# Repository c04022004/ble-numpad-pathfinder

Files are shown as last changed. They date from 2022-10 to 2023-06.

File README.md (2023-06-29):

# README.md

A pathfinder PCB for the upcoming Lipo-powered version of ESP32 BLE numpad. Arduino code also attached.

[Schematics PDF](./sch-export.pdf) | [Arduino Code](./arduino-freertos-code/ble_keyboard/ble_keyboard.ino) | [3D model](./3d-models/numpad-case-v10.3mf)

## Showcase

Assembled PCB  

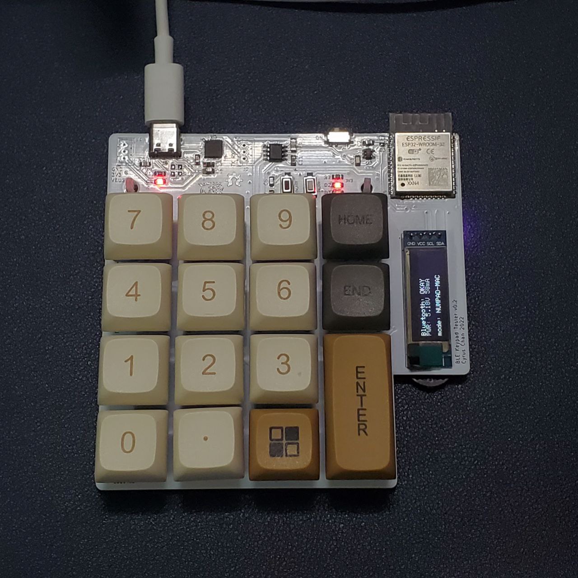
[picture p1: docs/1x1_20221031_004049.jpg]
  
</p>

Assembled PCB  w/ 3D print parts  

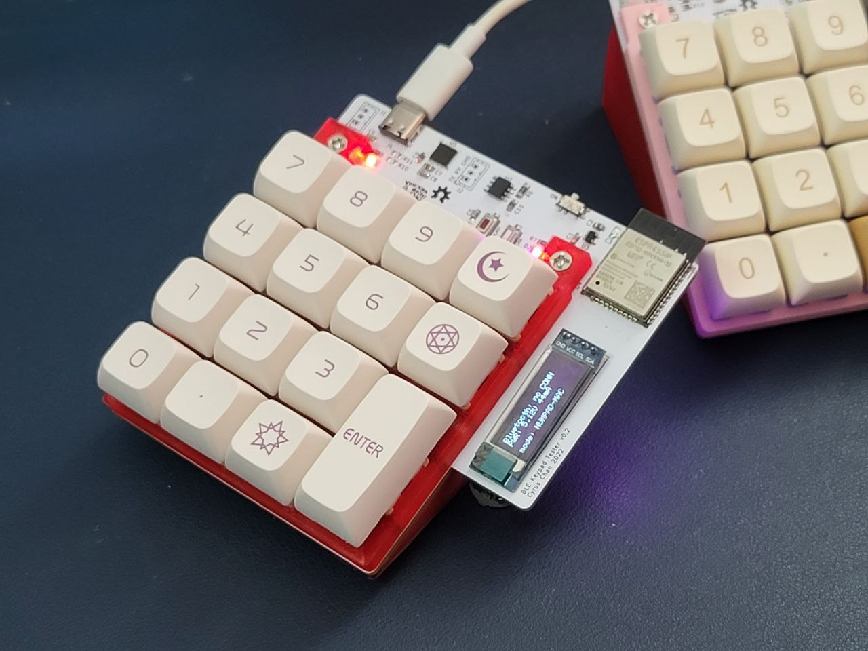
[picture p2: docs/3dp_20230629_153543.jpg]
  
</p>
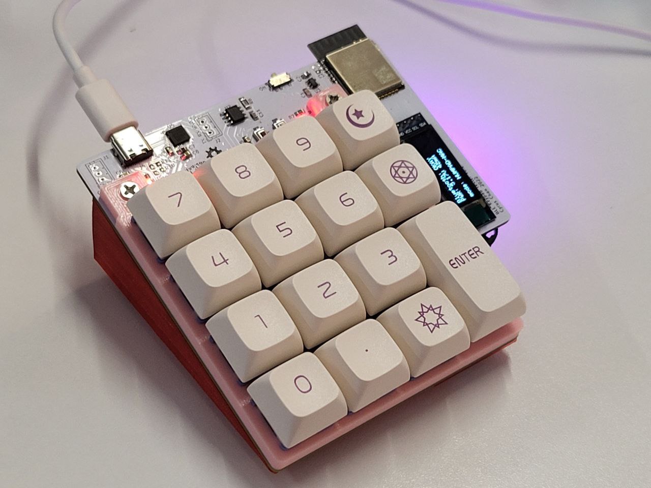
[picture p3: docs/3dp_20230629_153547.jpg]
  

## 3D-printed Parts

The two 3D printed parts (front plate & base) are fixed to the PCB asembly with 2pcs M3x20 screws.  
The parts are designed in Fusion360, and the exported files can be found at the [3d-models/](./3d-models/) folder.

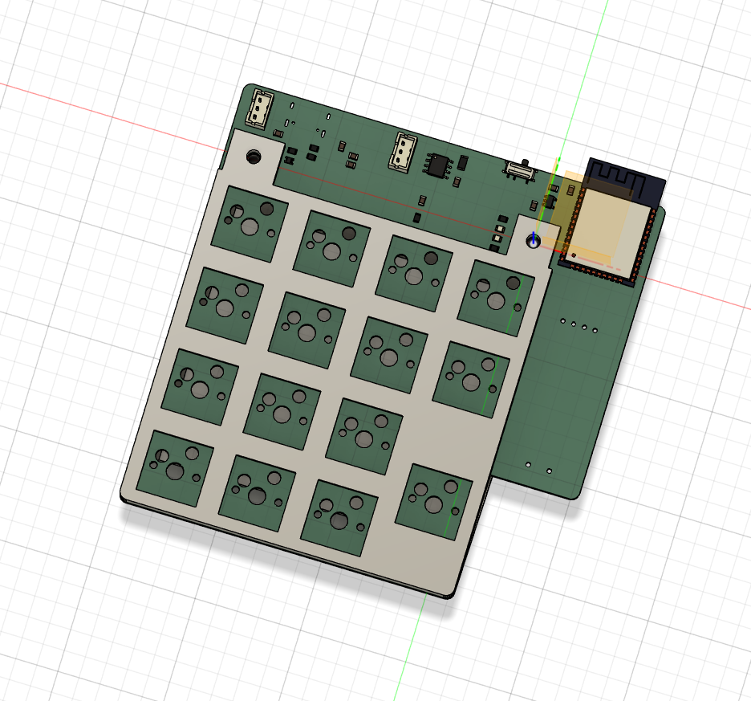
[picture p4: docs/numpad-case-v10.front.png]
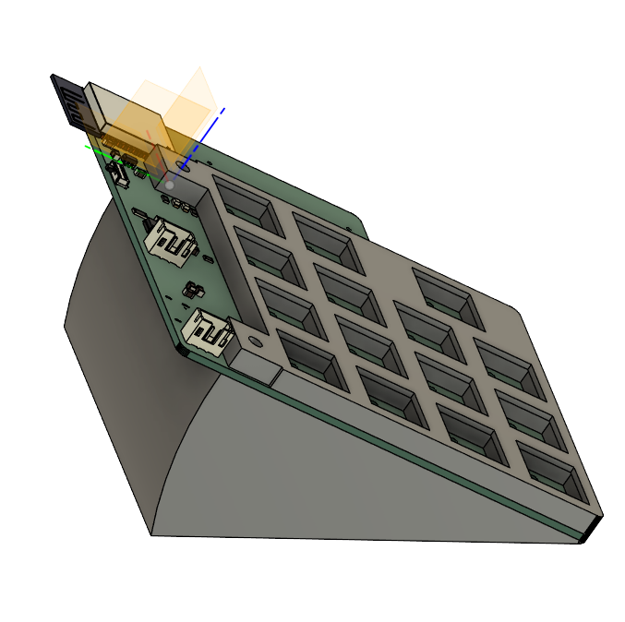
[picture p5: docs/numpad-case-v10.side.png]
 

## Known Problems
- ~~USB Type-C CC pins was lay out incorrectly~~ (still testing, maybe a USB cable compat issue)
    - Reason: CC pins should be connected to `GND` with `5.1kΩ` resistor per USB Type-C definition ([link1](https://community.silabs.com/s/article/what-s-the-role-of-cc-pin-in-type-c-solution?language=en_US) [link2](https://community.silabs.com/s/article/legacy-usb-device-detection-by-type-c?language=en_US))
    - Temporary fix: not populating `R10` & `R11`, might led to inability to connect when Type-C plug is flipped
- WS2812 data line `DIN` might be affected my noise
    - Problem: Should add a `500Ω` resistor in series on `DIN` line to improve signal reliability, as per NeoPixel UberGuide
    - Temporary fix: avoid changing CPU frequency scaling on-the-fly, which may affect GPIO line conditions
- TCA8418 IC is not intended to be use with key matrix and diodes
    - Reason: originally designed for (pathfinding) swapping in diode and check the effect of ghosting
    - Temporary fix: populate diode components with `0805 0Ω` resistors
- Hotplug shoe for keyswitch is not strong enough to hold it in place
    - Reason: there is no faceplate to hold/align the keyswitches
    - Temporary fix: use 5-pin version of keyswitches for added stability, use hotglue if necessary
    - **NEW**: use a 3d printed positioning plate uploaded [here](./3d-models/)

Hopefully all issues can be fixed in the next revision to the PCB.

## Credits

I used & referenced a lot from the design from the other open-source projects.  
Here is the list of git repos:  

### KiCAD
- https://github.com/keebio/keebio-components
- https://github.com/keebio/Keebo-Parts.pretty
- https://github.com/perigoso/keyswitch-kicad-library
- https://github.com/ebastler/marbastlib
- https://github.com/AnthonyDiGirolamo/i2c-thumb-keyboard
- https://github.com/gorbachev/KiCad-SSD1306-0.91-OLED-4pin-128x32.pretty
- https://github.com/sparkfun/SparkFun-KiCad-Libraries
- https://github.com/Digi-Key/digikey-kicad-library

### Arduino/FreeRTOS
- https://github.com/kitesurfer1404/WS2812FX
- https://github.com/greiman/SSD1306Ascii
- https://github.com/adafruit/Adafruit_INA219
- https://github.com/adafruit/Adafruit_TCA8418
- https://github.com/espressif/arduino-esp32
- https://www.freertos.org/a00113.html

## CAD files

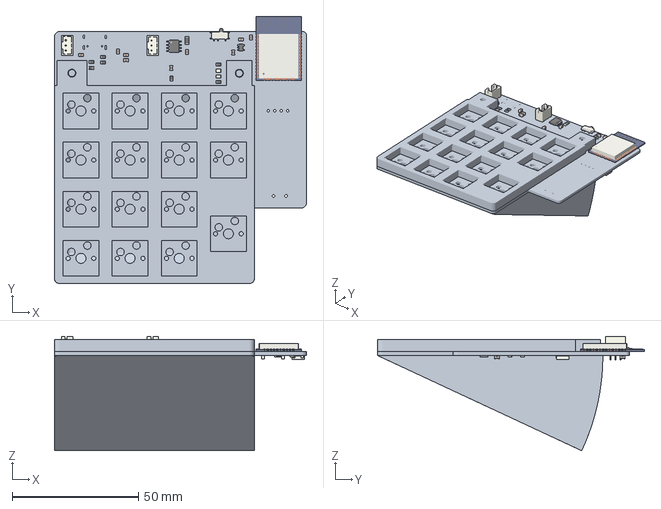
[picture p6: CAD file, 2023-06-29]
3d-models/numpad-case-v10.3mf
100.0 x 106.0 x 45.4 mm

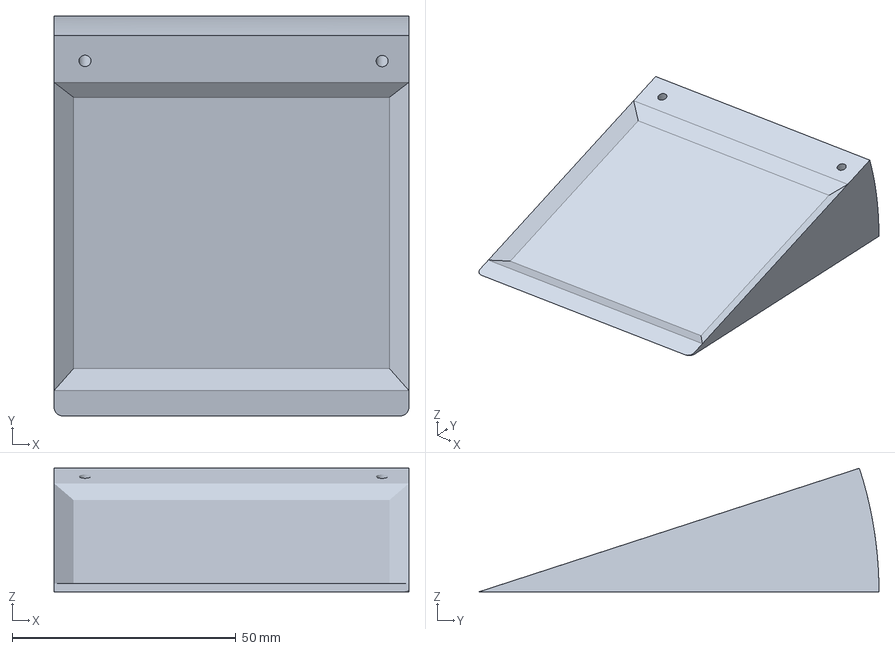
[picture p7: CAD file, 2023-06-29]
3d-models/KK_numpad-case-base-18.3mf
79.3 x 89.4 x 27.6 mm

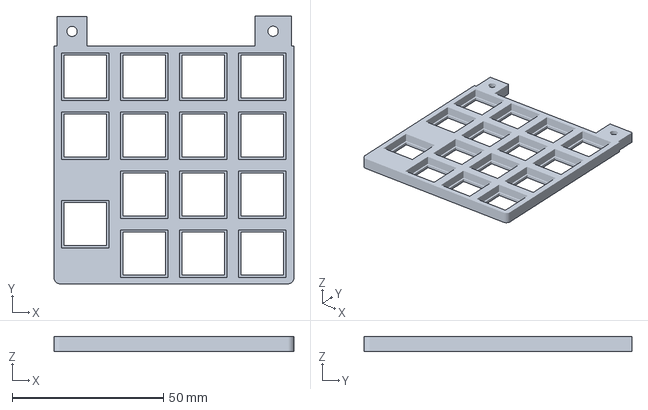
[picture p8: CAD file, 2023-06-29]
3d-models/KK_numpad-case-front-plate.3mf
79.3 x 88.5 x 4.80 mm

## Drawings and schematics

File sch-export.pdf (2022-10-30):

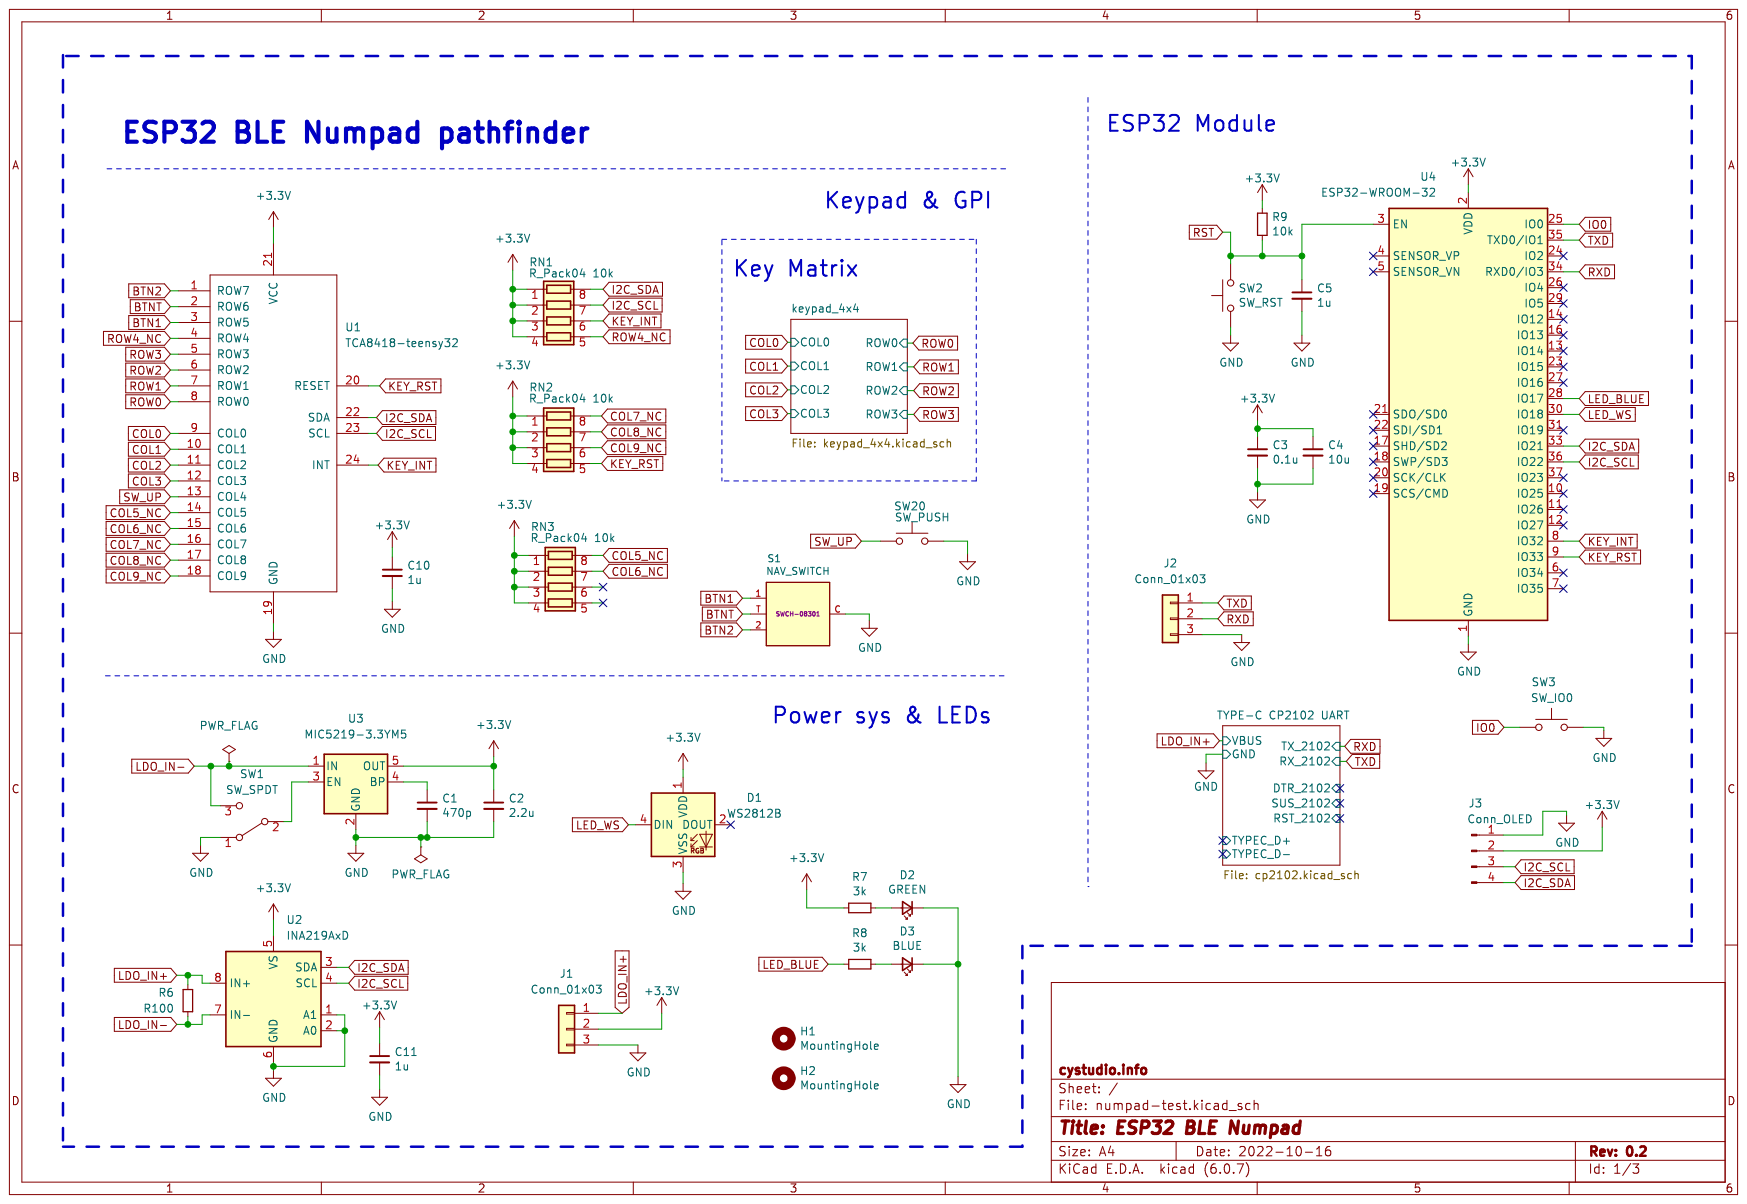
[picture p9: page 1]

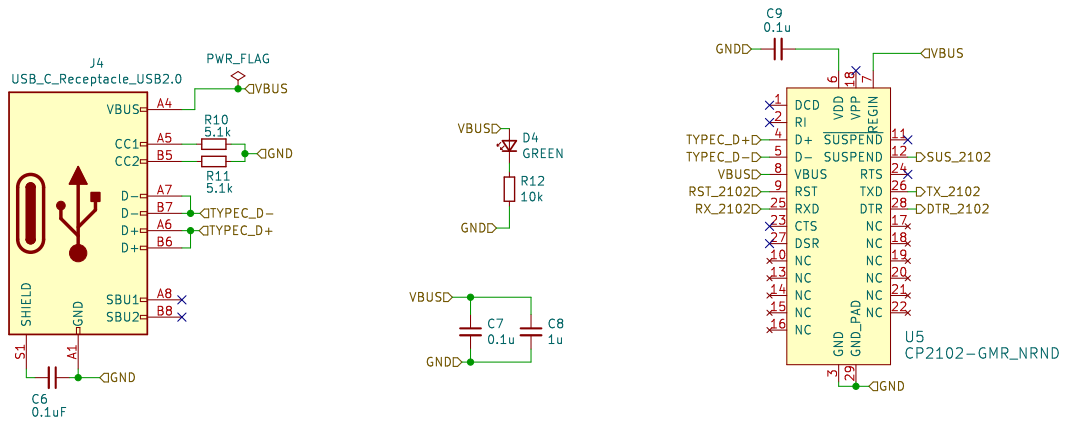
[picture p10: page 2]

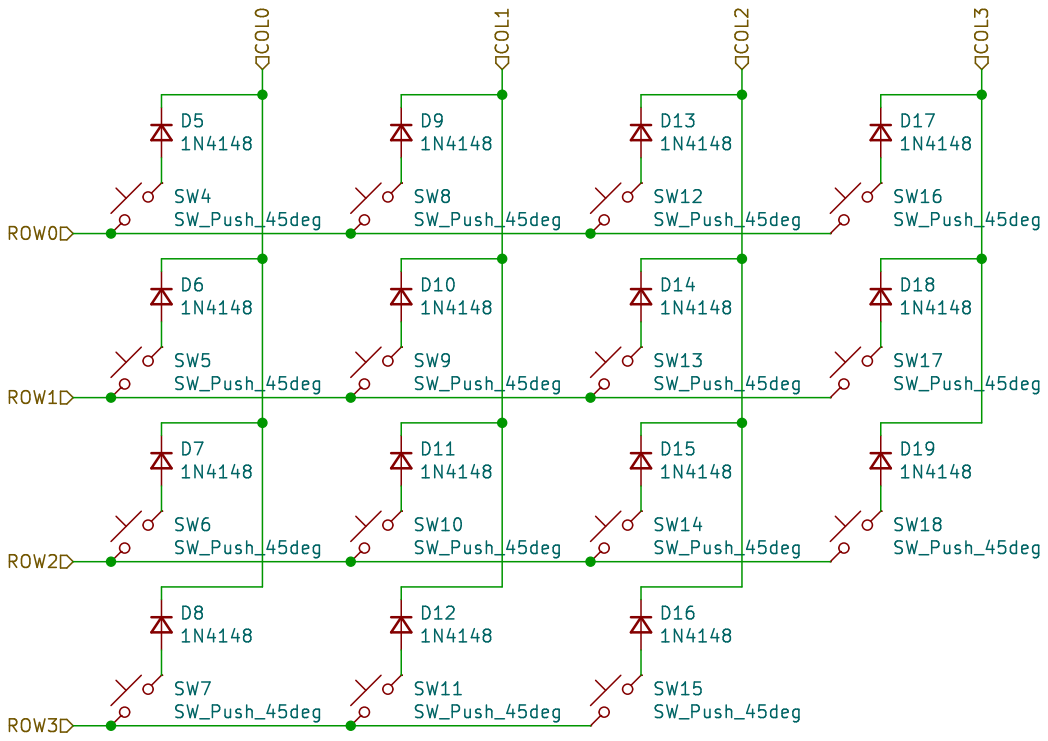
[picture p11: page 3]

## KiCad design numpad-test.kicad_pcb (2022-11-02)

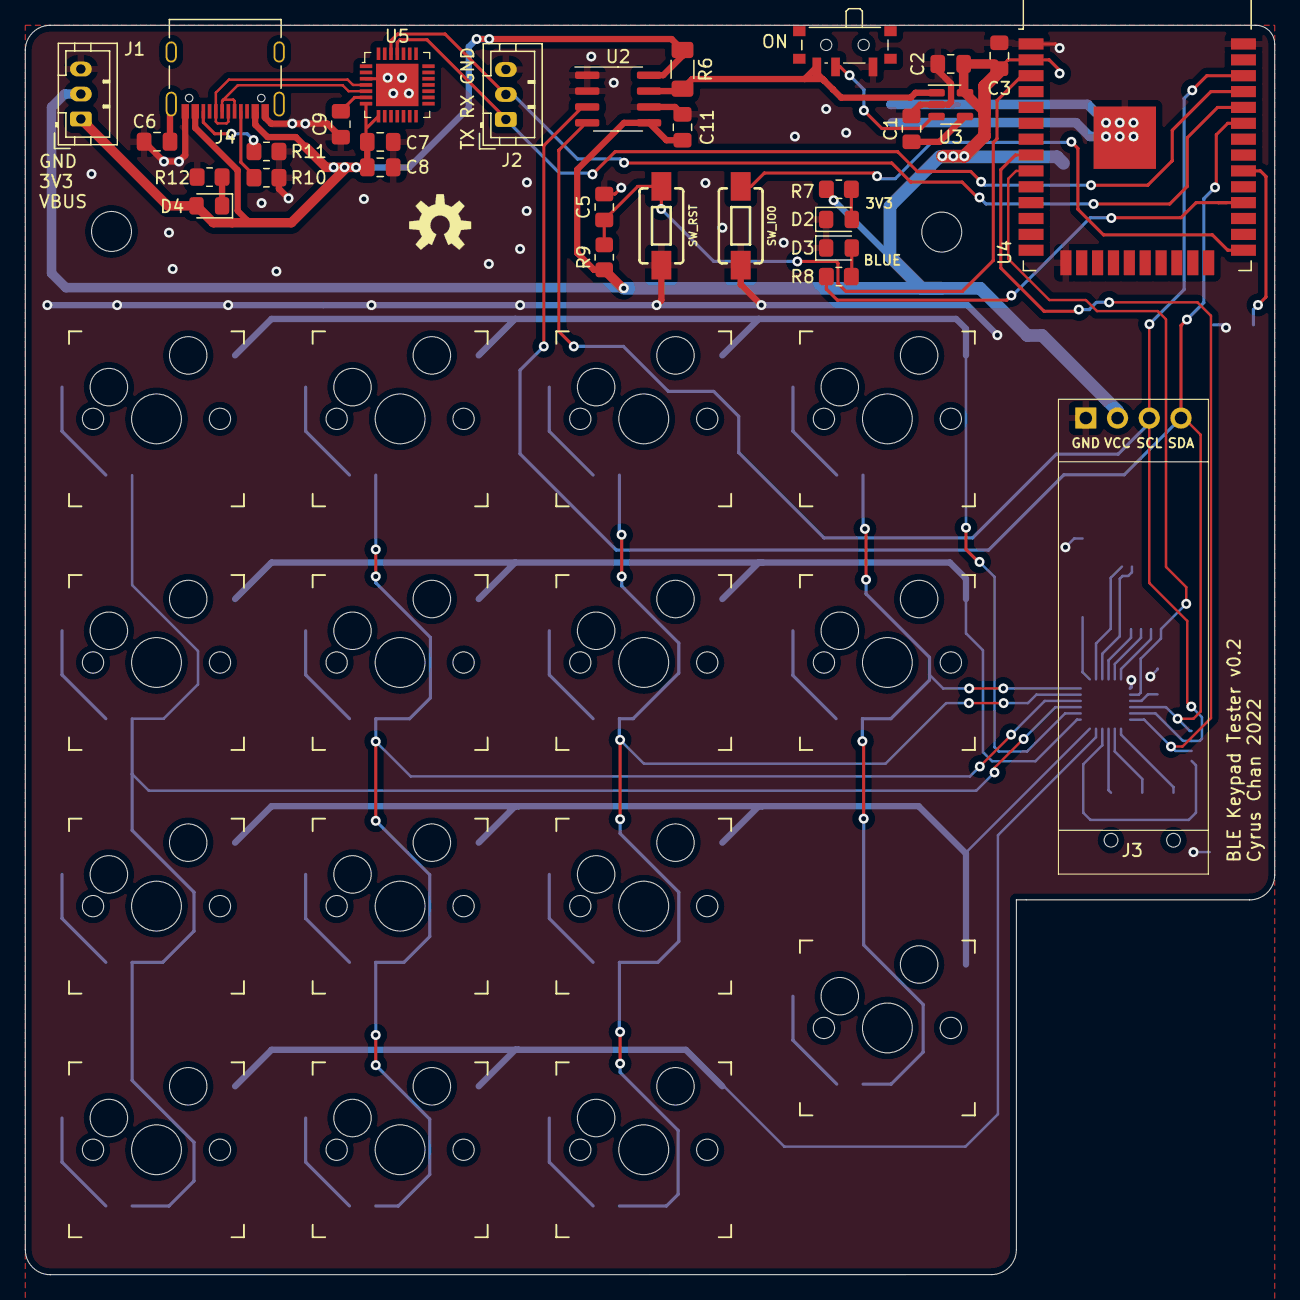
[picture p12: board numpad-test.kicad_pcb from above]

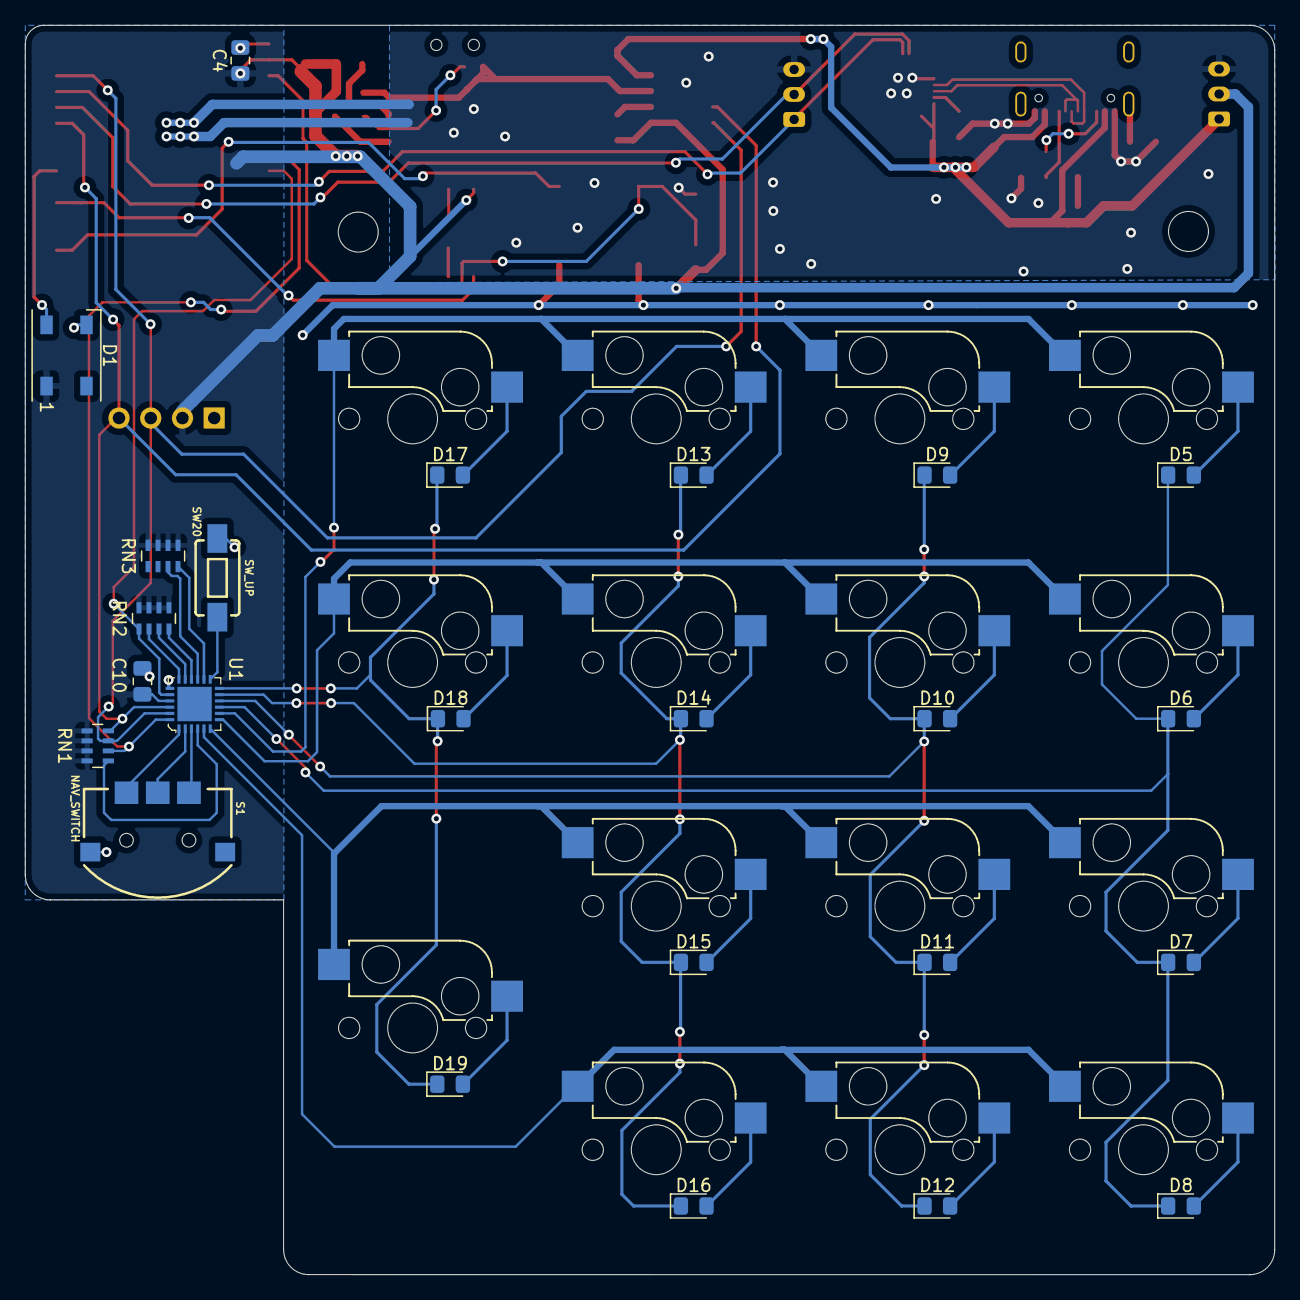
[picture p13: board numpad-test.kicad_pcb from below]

Board: 2 copper layers, 100.0 x 100.0 mm, 71 parts (24 on the bottom side), 58 nets.

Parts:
C1: 470p; C_0805_2012Metric_Pad1.18x1.45mm_HandSolder
C2: 2.2u; C_0805_2012Metric_Pad1.18x1.45mm_HandSolder
C3, C7, C9: 0.1u; C_0805_2012Metric_Pad1.18x1.45mm_HandSolder
C4: 10u; C_0805_2012Metric_Pad1.18x1.45mm_HandSolder
C5, C8, C10, C11: 1u; C_0805_2012Metric_Pad1.18x1.45mm_HandSolder
C6: 0.1uF; C_0805_2012Metric_Pad1.18x1.45mm_HandSolder
D1: WS2812B; LED_WS2812B_PLCC4_5.0x5.0mm_P3.2mm
D2: GREEN; LED_0805_2012Metric_Pad1.15x1.40mm_HandSolder
D3: BLUE; LED_0805_2012Metric_Pad1.15x1.40mm_HandSolder
D4: GREEN; D_0805_2012Metric_Pad1.15x1.40mm_HandSolder
D5, D6, D7, D8, D9, D10, D11, D12, D13, D14, D15, D16, D17, D18, D19: 1N4148; D_0805_2012Metric_Pad1.15x1.40mm_HandSolder
H1, H2: MountingHole; MountingHole_3.2mm_M3
J1, J2: Conn_01x03; JST_PH_B3B-PH-K_1x03_P2.00mm_Vertical
J3: Conn_OLED; SSD1306-0.91-OLED-4pin-128x32
J4: USB_C_Receptacle_USB2.0; USB_C_Receptacle_Palconn_UTC16-G
R6: R100; R_1206_3216Metric_Pad1.30x1.75mm_HandSolder
R7, R8: 3k; R_0805_2012Metric_Pad1.20x1.40mm_HandSolder
R9, R12: 10k; R_0805_2012Metric_Pad1.20x1.40mm_HandSolder
R10, R11: 5.1k; R_0805_2012Metric_Pad1.20x1.40mm_HandSolder
RN1, RN2, RN3: R_Pack04 10k; R_Array_Concave_4x0603
S1: NAV_SWITCH
SW1: SW_SPDT; SW_SPDT_PCM12
SW2: SW_RST; TACTILE_SWITCH_SMD_6.0X3.5MM
SW3: SW_IO0; TACTILE_SWITCH_SMD_6.0X3.5MM
SW4, SW5, SW6, SW7, SW8, SW9, SW10, SW11, SW12, SW13, SW14, SW15, SW16, SW17, SW18: SW_Push_45deg; Kailh_socket_MX
SW20: SW_UP; TACTILE_SWITCH_SMD_6.0X3.5MM
U1: TCA8418-teensy32; WQFN-24-1EP_4x4mm
U2: INA219AxD; SOIC-8_3.9x4.9mm_P1.27mm
U3: MIC5219-3.3YM5; SOT-23-5
U4: ESP32-WROOM-32
U5: CP2102-GMR_NRND; VFQFN-28-1EP_5x5mm

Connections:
+3.3V: C2.1, C3.1, C4.1, C10.1, C11.1, D1.1 (VDD), J1.2, J3.2, R7.2, R9.1, RN1.1 (R1.1), RN1.2 (R2.1), RN1.3 (R3.1), RN1.4 (R4.1), RN2.1 (R1.1), RN2.2 (R2.1), RN2.3 (R3.1), RN2.4 (R4.1), RN3.1 (R1.1), RN3.2 (R2.1), RN3.3 (R3.1), RN3.4 (R4.1), U1.21 (VCC), U2.5 (VS), U3.5 (OUT), U4.2 (VDD)
/TYPE-C CP2102 UART/TYPEC_D+: J4.A6 (D+), J4.B6 (D+), U5.4 (D+)
/TYPE-C CP2102 UART/TYPEC_D-: J4.A7 (D-), J4.B7 (D-), U5.5 (D-)
BTN1: S1.1, U1.3 (ROW5)
BTN2: S1.2, U1.1 (ROW7)
BTNT: S1.T, U1.2 (ROW6)
COL0: D5.1 (K), D6.1 (K), D7.1 (K), D8.1 (K), U1.9 (COL0)
COL1: D9.1 (K), D10.1 (K), D11.1 (K), D12.1 (K), U1.10 (COL1)
COL2: D13.1 (K), D14.1 (K), D15.1 (K), D16.1 (K), U1.11 (COL2)
COL3: D17.1 (K), D18.1 (K), D19.1 (K), U1.12 (COL3)
COL5_NC: RN3.8 (R1.2), U1.14 (COL5)
COL6_NC: RN3.7 (R2.2), U1.15 (COL6)
COL7_NC: RN2.8 (R1.2), U1.16 (COL7)
COL8_NC: RN2.7 (R2.2), U1.17 (COL8)
COL9_NC: RN2.6 (R3.2), U1.18 (COL9)
GND: C1.2, C2.2, C3.2, C4.2, C5.2, C6.1, C7.2, C8.2, C9.1, C10.2, C11.2, D1.3 (VSS), D2.1 (K), D3.1 (K), J1.3, J2.3, J3.1, J4.A1 (GND), J4.A12 (GND), J4.B1 (GND), J4.B12 (GND), R10.2, R11.1, R12.2, S1.C, SW1.1 (A), SW2.1, SW3.2, SW20.2, U1.19 (GND), U2.1 (A1), U2.2 (A0), U2.6 (GND), U3.2 (GND), U4.1 (GND), U4.15 (GND), U4.38 (GND), U4.39 (GND), U5.3 (GND), U5.29 (GND_PAD)
I2C_SCL: J3.3, RN1.7 (R2.2), U1.23 (SCL), U2.4 (SCL), U4.36 (IO22)
I2C_SDA: J3.4, RN1.8 (R1.2), U1.22 (SDA), U2.3 (SDA), U4.33 (IO21)
IO0: SW3.1, U4.25 (IO0)
KEY_INT: RN1.6 (R3.2), U1.24 (INT), U4.8 (IO32)
KEY_RST: RN2.5 (R4.2), U1.20 (RESET), U4.9 (IO33)
LDO_IN+: C7.1, C8.1, D4.2 (A), J1.1, J4.A4 (VBUS), J4.A9 (VBUS), J4.B4 (VBUS), J4.B9 (VBUS), R6.1, U2.8 (IN+), U5.7 (REGIN), U5.8 (VBUS)
LDO_IN-: R6.2, SW1.3 (C), U2.7 (IN-), U3.1 (IN)
LED_BLUE: R8.2, U4.28 (IO17)
LED_WS: D1.4 (DIN), U4.30 (IO18)
unnamed: C1.1, U3.4 (BP)
unnamed: C6.2, J4.S1 (SHIELD)
unnamed: C9.2, U5.6 (VDD)
unnamed: D2.2 (A), R7.1
unnamed: D3.2 (A), R8.1
unnamed: D4.1 (K), R12.1
unnamed: D5.2 (A), SW4.2
unnamed: D6.2 (A), SW5.2
unnamed: D7.2 (A), SW6.2
unnamed: D8.2 (A), SW7.2
unnamed: D9.2 (A), SW8.2
unnamed: D10.2 (A), SW9.2
unnamed: D11.2 (A), SW10.2
unnamed: D12.2 (A), SW11.2
unnamed: D13.2 (A), SW12.2
unnamed: D14.2 (A), SW13.2
unnamed: D15.2 (A), SW14.2
unnamed: D16.2 (A), SW15.2
unnamed: D17.2 (A), SW16.2
unnamed: D18.2 (A), SW17.2
unnamed: D19.2 (A), SW18.2
unnamed: J4.A5 (CC1), R10.1
unnamed: J4.B5 (CC2), R11.2
unnamed: SW1.2 (B), U3.3 (EN)
ROW0: SW4.1, SW8.1, SW12.1, SW16.1, U1.8 (ROW0)
ROW1: SW5.1, SW9.1, SW13.1, SW17.1, U1.7 (ROW1)
ROW2: SW6.1, SW10.1, SW14.1, SW18.1, U1.6 (ROW2)
ROW3: SW7.1, SW11.1, SW15.1, U1.5 (ROW3)
ROW4_NC: RN1.5 (R4.2), U1.4 (ROW4)
RST: C5.1, R9.2, SW2.2, U4.3 (EN)
RXD: J2.2, U4.34 (RXD0/IO3), U5.26 (TXD)
SW_UP: SW20.1, U1.13 (COL4)
TXD: J2.1, U4.35 (TXD0/IO1), U5.25 (RXD)

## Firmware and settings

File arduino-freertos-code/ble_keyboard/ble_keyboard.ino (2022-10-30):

#include <BleKeyboard.h>
BleKeyboard bleKeyboard("ESP32-numpad", "cystudio", 100);
bool ble_connected = false;
bool ble_sleep = false;
bool prep_deepsleep = false;
unsigned int ble_connect_retries = 0;
unsigned long last_keypress_ms = 0;

// RTOS structs
TaskHandle_t Handle_TaskLedBlink;
TaskHandle_t Handle_TaskWS2812;
TaskHandle_t Handle_TaskSSD1306;
TaskHandle_t Handle_TaskINA219;
TaskHandle_t Handle_TaskTCA8418;

SemaphoreHandle_t serialMutex;
SemaphoreHandle_t wireMutex;
SemaphoreHandle_t bleMutex;

// Shared variables

// SemaphoreHandle_t pwrMutex;
#include <movingAvg.h>
movingAvg avgV(12),avgI(12),avgPWR(12);
float busvoltage = 0;
float current_mA = 0;
float power_mW = 0;

//SemaphoreHandle_t ledMutex;
bool ws_led_off = false;
uint8_t ws_color = 0;
uint32_t ws_mode = 0;

//SemaphoreHandle_t keyMutex;
const byte ROWS = 4;
const byte COLS = 4;
const char keys_norm[ROWS][COLS] = {
  {KEY_NUM_7,KEY_NUM_8,KEY_NUM_9,KEY_BACKSPACE},
  {KEY_NUM_4,KEY_NUM_5,KEY_NUM_6,KEY_DELETE},
  {KEY_NUM_1,KEY_NUM_2,KEY_NUM_3,KEY_NUM_ENTER},
  {KEY_NUM_0,KEY_NUM_PERIOD,KEY_F24,KEY_F24}, 
};
const char keys_numlock[ROWS][COLS] = {
  {KEY_HOME,KEY_UP_ARROW,KEY_PAGE_UP,KEY_F24},
  {KEY_LEFT_ARROW,KEY_F24,KEY_RIGHT_ARROW,KEY_F24},
  {KEY_END,KEY_DOWN_ARROW,KEY_PAGE_DOWN,KEY_RETURN},
  {KEY_INSERT,KEY_DELETE,KEY_F24,KEY_F24},
};
const char keys_funct[ROWS][COLS] = {
  {KEY_HOME,KEY_UP_ARROW,KEY_END,KEY_PAGE_UP},
  {KEY_LEFT_ARROW,KEY_DOWN_ARROW,KEY_RIGHT_ARROW,KEY_PAGE_DOWN},
  {KEY_F24,KEY_F24,KEY_F24,KEY_RIGHT_SHIFT},
  {KEY_F24,KEY_F24,KEY_F24,KEY_F24},
//  {'C-c','C-v',KEY_ESC,KEY_LEFT_SHIFT},
//  {'C-z','C-up',KEY_F24,KEY_F24}, 
};
const char (*kpd_layout)[ROWS][COLS] = &keys_norm;
String kpd_mode;
bool mac_shortcut = true;


/*
 * LED update section:
 * Blue LED (IO17), WS2812 LED (IO18)
 */

// Assign alias to GPIO pins
#define LED_B 17
#define CH_LED_B 1

static void TaskBlink(void *pvParameters) {

  // ESP32 specific methods for LED pwm
  ledcAttachPin(LED_B, CH_LED_B); ledcSetup(CH_LED_B, 12000, 8);

  //                                                                                                                                                                                                                                                                                                              byte intensity=0;
  for(;;) {
    if(prep_deepsleep){ledcWrite(CH_LED_B, 20);break;}
    //if(ble_sleep){
    //  // 4-second breathing cycle
    //  for(intensity=0;intensity<150;intensity+=1){
    //    ledcWrite(CH_LED_B, intensity);
    //    vTaskDelay(10/portTICK_PERIOD_MS);
    //  }
    //  for(;intensity>0;intensity-=1){
    //    ledcWrite(CH_LED_B, intensity);
    //    vTaskDelay(10/portTICK_PERIOD_MS);
    //  }
    //  ledcWrite(CH_LED_B, 0);
    //  vTaskDelay(600/portTICK_PERIOD_MS);
    //}
    if(!ble_connected){
      // 2-second sequence
      ledcWrite(CH_LED_B, 75);
      vTaskDelay(1000/portTICK_PERIOD_MS);
      ledcWrite(CH_LED_B, 20);
      vTaskDelay(1000/portTICK_PERIOD_MS);
    }else{ // ble_connected==true
      // 2-second beep-beep sequence
      ledcWrite(CH_LED_B, 75);
      vTaskDelay(150/portTICK_PERIOD_MS);
      ledcWrite(CH_LED_B, 0);
      vTaskDelay(50/portTICK_PERIOD_MS);
      ledcWrite(CH_LED_B, 75);
      vTaskDelay(150/portTICK_PERIOD_MS);
      ledcWrite(CH_LED_B, 0);
      vTaskDelay(1150/portTICK_PERIOD_MS);
    }
  }
  vTaskDelete(NULL);
}

#include <WS2812FX.h>
#define WS_LED_COUNT 1
#define WS_LED_PIN 18
#define WS_COLOR_CHOICE 10

uint32_t ws_clist[WS_COLOR_CHOICE] = {
  RED, GREEN, BLUE, WHITE, YELLOW,
  CYAN, MAGENTA, PURPLE, ORANGE, PINK
};

WS2812FX ws2812fx = WS2812FX(
  WS_LED_COUNT, WS_LED_PIN,
  NEO_GRB + NEO_KHZ800
);

static void TaskWs2812Update(void *pvParameters) {

  // Library init
  ws_color = 6; // MAGENTA
  ws_mode = FX_MODE_BREATH;
  ws2812fx.init();
  ws2812fx.setBrightness(75);
  ws2812fx.setSpeed(20);
  ws2812fx.setColor(ws_clist[ws_color]);
  ws2812fx.setMode(ws_mode);
  ws2812fx.start();

  for(;;) {
    if(prep_deepsleep || ws_led_off){
      ws2812fx.setColor(BLACK);
      vTaskDelay(90/portTICK_PERIOD_MS);
    }else{
      ws2812fx.setColor(ws_clist[ws_color]);
    }
    ws2812fx.service();
    vTaskDelay(10/portTICK_PERIOD_MS);
  }
  vTaskDelete(NULL);
}


/*
 * I2C update section: INA219, SSD1306, TCA4818
 * "SemaphoreHandle_t wireMutex" use aquire mutex before lib calls
 */
#include <Wire.h>

#include "SSD1306Ascii.h"
#include "SSD1306AsciiWire.h"

#define I2C_ADDRESS 0x3C
SSD1306AsciiWire oled;
uint8_t oledfields[10];

#define SSD1306_DISPLAYOFF 0xAE
void oled_powersave(void){
    Wire.beginTransmission(I2C_ADDRESS);
    Wire.write((uint8_t)0x00);
    Wire.write((uint8_t)SSD1306_DISPLAYOFF);
    Wire.endTransmission();
}

#define SSD1306_SETCONTRAST 0x81
void oled_dim(void){
    Wire.beginTransmission(I2C_ADDRESS);
    Wire.write((uint8_t)0x00);
    Wire.write((uint8_t)SSD1306_SETCONTRAST);
    Wire.endTransmission();
}

static void TaskOledUpdate(void *pvParameters) {
  
  // Initialize ssd1306 via i2c
  
  xSemaphoreTake(wireMutex, portMAX_DELAY);
  oled.begin(&Adafruit128x32, I2C_ADDRESS);
  oled.setFont(Adafruit5x7); oled.set1X();
  oled.displayRemap(true);oled_dim();
  oled.clear();
  oledfields[0] = oled.fieldWidth(strlen("Bluetooth: "));
  oled.println("Bluetooth: no CONN");
  oledfields[1] = oled.fieldWidth(strlen("PWR: "));
  oled.println("PWR: 0.00V 000mA");
  
  oled.println(""); oled.println("mode: NUMPAD");
  oledfields[2] = oled.fieldWidth(strlen("mode: "));
  xSemaphoreGive(wireMutex);
  vTaskDelay(10/portTICK_PERIOD_MS);
  
  for(;;) {
    xSemaphoreTake(wireMutex, portMAX_DELAY);
    
    oled.setCursor(oledfields[0], 0);
    if(ble_connected){
      oled.print("OKAY");oled.clearToEOL();
    }else{
      oled.print("no CONN");oled.clearToEOL();
    }

    oled.setCursor(oledfields[1], 1);
    if(avgV.getCount()>0 && avgI.getCount()>0){
      oled.print(avgV.getAvg()/(float)1000, 2);oled.print("V ");
      oled.print(avgI.getAvg(), 0);oled.print("mA");
      oled.clearToEOL();
    }
    
    oled.clearField(oledfields[2], 3, 1);
    if(kpd_layout==&keys_norm){kpd_mode="NUMPAD";}
    else if(kpd_layout==&keys_numlock){kpd_mode="NUMLOCK";}
    else if(kpd_layout==&keys_funct){kpd_mode="FUNCT";}
    if(ble_sleep){kpd_mode="SLEEP";}
    oled.print(kpd_mode);
    if(mac_shortcut){oled.print("-MAC");}
    oled.clearToEOL();

    xSemaphoreGive(wireMutex);

    vTaskDelay(200/portTICK_PERIOD_MS);
  }
  vTaskDelete(NULL);
}

#include <Adafruit_INA219.h>

Adafruit_INA219 ina219;

static void TaskIna219Update(void *pvParameters) {

  // Initialize ina219 via i2c
  xSemaphoreTake(wireMutex, portMAX_DELAY);
  ina219.begin();
  ina219.setCalibration_16V_400mA();
  xSemaphoreGive(wireMutex);
  avgV.begin();avgI.begin();avgPWR.begin();
  vTaskDelay(10/portTICK_PERIOD_MS);

  for(;;) {
    // Get reading from INA219
    xSemaphoreTake(wireMutex, portMAX_DELAY);
    busvoltage = ina219.getBusVoltage_V();  avgV.reading(busvoltage*1000);
    current_mA = ina219.getCurrent_mA();    avgI.reading(current_mA);
    power_mW = ina219.getPower_mW();        avgPWR.reading(power_mW);
    xSemaphoreGive(wireMutex);

    vTaskDelay(20/portTICK_PERIOD_MS);
  }
  vTaskDelete(NULL);
}

/*
 * Keypad conversion section:
 * 4*4 matrix + 4 push btn
 * 
 * 15 actual keys, C-Enter to change mode
 * uses KEY_F24 to represent no-op
 */

#include <Adafruit_TCA8418.h>

#define TCA8418_INT 32
#define TCA8418_RST 33
Adafruit_TCA8418 keypad;
volatile bool tca8418_event = 0;

void IRAM_ATTR tca8418_irq(){
  tca8418_event=true;
}

void process_gpio(int k, int colrow){
  switch(colrow){
    case 101: // NAV_UP
      if(k&0x80){
        ws_color=(ws_color+1)%WS_COLOR_CHOICE;
      }
      break;
    case 102: // NAV_ENTER
      if(k&0x80){
        ws_led_off=!ws_led_off;
      }
      break;
    case 103: // NAV_DOWN
      if(k&0x80){
        ws_color=(ws_color-1+WS_COLOR_CHOICE)%WS_COLOR_CHOICE;
      }
      break;
    case 108: // PUSH_SW
      if(k&0x80){
        mac_shortcut=!mac_shortcut;
      }
      break;
  }
}

static void TaskTca8418Update(void *pvParameters) {

  // Setup isr/irq for TCA8418
  pinMode(TCA8418_INT, INPUT);
  attachInterrupt(digitalPinToInterrupt(TCA8418_INT), tca8418_irq, FALLING);

  // Initialize tca8418 via i2c
  xSemaphoreTake(wireMutex, portMAX_DELAY);
  keypad.begin(TCA8418_DEFAULT_ADDR, &Wire);
  keypad.matrix(4, 4); keypad.flush();
  keypad.enableInterrupts();
  xSemaphoreGive(wireMutex);
  vTaskDelay(10/portTICK_PERIOD_MS);

  bool fn_btnp = false; // button pressed?

  for(;;) {
    if(tca8418_event){
      xSemaphoreTake(wireMutex, portMAX_DELAY);
      int intStat = keypad.readRegister(TCA8418_REG_INT_STAT);
      if (intStat & 0x02){ // mandated
        keypad.readRegister(TCA8418_REG_GPIO_INT_STAT_1);
        keypad.readRegister(TCA8418_REG_GPIO_INT_STAT_2);
        keypad.readRegister(TCA8418_REG_GPIO_INT_STAT_3);
        keypad.writeRegister(TCA8418_REG_INT_STAT, 2);
      }
  
      while(keypad.available() > 0){
        int k = keypad.getEvent();
        int colrow = (k&0x7F)-1;
        last_keypress_ms = millis();
        
        if(colrow>96){ // gpio range
          process_gpio(k, colrow);
          continue;
        }

        if(colrow==32){ // r3c2: fn btn
          fn_btnp = k&0x80;
          if(fn_btnp){kpd_layout=&keys_funct;}
          else{kpd_layout=&keys_norm;}
        }

        if(!ble_connected){continue;}
        if(xSemaphoreTake(bleMutex,(TickType_t)50)==pdTRUE){
          char keycode = (*kpd_layout)[colrow/10][colrow%10];
          if (keycode==KEY_F24){
            // no-op, or check for combos
            if(fn_btnp&&(k&0x80)){
              switch(colrow){
                case 30:
                  bleKeyboard.press(mac_shortcut?KEY_LEFT_GUI:KEY_LEFT_CTRL);
                  bleKeyboard.press('z');
                  break;
                case 31:
                  bleKeyboard.press(KEY_LEFT_GUI);
                  bleKeyboard.press(mac_shortcut?KEY_UP_ARROW:KEY_TAB);
                  break;
                case 20:
                  bleKeyboard.press(mac_shortcut?KEY_LEFT_GUI:KEY_LEFT_CTRL);
                  bleKeyboard.press('c');
                  break;
                case 21:
                  bleKeyboard.press(mac_shortcut?KEY_LEFT_GUI:KEY_LEFT_CTRL);
                  bleKeyboard.press('v');
                  break;
                case 22:
                  bleKeyboard.press(KEY_ESC);
                  break;
                case 23:
                  // bleKeyboard.press(KEY_RIGHT_SHIFT);
                  break;
              }
              vTaskDelay(1/portTICK_PERIOD_MS);
              bleKeyboard.releaseAll();
            }else if((colrow==32)&&!(k&0x80)){
              bleKeyboard.releaseAll();
            }
          }else if(k&0x80){ //PRESS
            bleKeyboard.press(keycode);
          }else{ //RELEASE
            bleKeyboard.release(keycode);
          }
          xSemaphoreGive(bleMutex);
        }
        
      }
      
      keypad.writeRegister(TCA8418_REG_INT_STAT, 1);
      if(!(keypad.readRegister(TCA8418_REG_INT_STAT)&0x03)){
        // Check again no pending events
        tca8418_event = false;
      }
      xSemaphoreGive(wireMutex);
    }

    vTaskDelay(2/portTICK_PERIOD_MS);
  }
  vTaskDelete(NULL);
}

/*
 * Deepsleep config section:
 * Serial mostly on this core to avoid using mutex
 * CPU set to 80MHz to save on power
 */

RTC_DATA_ATTR int bootCount = 0;

void print_wakeup_reason(){
  esp_sleep_wakeup_cause_t wakeup_reason;

  wakeup_reason = esp_sleep_get_wakeup_cause();

  switch(wakeup_reason){
    case ESP_SLEEP_WAKEUP_EXT0 : Serial.println("Wakeup caused by external signal using RTC_IO"); break;
    case ESP_SLEEP_WAKEUP_EXT1 : Serial.println("Wakeup caused by external signal using RTC_CNTL"); break;
    case ESP_SLEEP_WAKEUP_TIMER : Serial.println("Wakeup caused by timer"); break;
    case ESP_SLEEP_WAKEUP_TOUCHPAD : Serial.println("Wakeup caused by touchpad"); break;
    case ESP_SLEEP_WAKEUP_ULP : Serial.println("Wakeup caused by ULP program"); break;
    default : Serial.printf("Wakeup was not caused by deep sleep: %d\n",wakeup_reason); break;
  }
}

void peripheral_powersave(){
  // Implementing ESP32 "Modem Sleep"
  // https://www.mischianti.org/2021/03/10/esp32-power-saving-modem-and-light-sleep-2/
  prep_deepsleep = true;
  btStop(); bleKeyboard.end(); ble_connected=false;
  ble_sleep=true; vTaskDelay(500/portTICK_PERIOD_MS);
  ledcWrite(CH_LED_B, 0);ws2812fx.setColor(BLACK);
  xSemaphoreTake(wireMutex, portMAX_DELAY);
  ina219.powerSave(true);
  oled_powersave();
  xSemaphoreGive(wireMutex);
  vTaskDelay(500/portTICK_PERIOD_MS);
}



void genDeviceName(char* deviceName, char* devicePrefix) {
  // https://github.com/T-vK/ESP32-BLE-Keyboard/issues/178
  // populates the deviceName char with the device Prefix plus a "unique" 4 char code
  uint64_t chipid = ESP.getEfuseMac();
  uint16_t shortid = chipid >> 32;
  char sprintfString[20] = "";
  strcat(sprintfString, devicePrefix);
  strcat(sprintfString, "%04X");
  sprintf(deviceName, sprintfString, shortid);
}



void setup() {

  // Initialize serial at 115200baud: same as debug msgs
  Serial.begin(115200);
  Serial.println("--- Bootstrap msgs ---");
  
  // Increment boot number and print it every reboot
  Serial.println("Boot counter: " + String(bootCount++));
  print_wakeup_reason();
  esp_sleep_enable_ext0_wakeup(GPIO_NUM_32,0);

  // Inspect RTOS core usage
  // Mutex declared, not used until loop() & vTask
  serialMutex = xSemaphoreCreateMutex();
  Serial.print("setup() running on core ");
  Serial.println(xPortGetCoreID());
  Serial.println();
  vTaskDelay(50/portTICK_PERIOD_MS);

  // Initialize I2C bus, together with mutex
  wireMutex = xSemaphoreCreateMutex();
  Wire.begin();
  Wire.setClock(400000L);
  vTaskDelay(50/portTICK_PERIOD_MS);

  // Initialize BLE keyboard, together with mutex
  bleMutex = xSemaphoreCreateMutex();
  char deviceName[20];
  genDeviceName(deviceName, "ESP32kp-");
  bleKeyboard.setName(deviceName);
  bleKeyboard.begin();
  vTaskDelay(50/portTICK_PERIOD_MS);

  // Attach RTOS task to actual cores
  xTaskCreatePinnedToCore(
      TaskBlink, /* Function to implement the task */
      "TaskBlink", /* Name of the task */
      10000,  /* Stack size in words */
      NULL,  /* Task input parameter */
      0,  /* Priority of the task */
      &Handle_TaskLedBlink,  /* Task handle. */
      0); /* Core where the task should run */

  xTaskCreatePinnedToCore(
      TaskOledUpdate, /* Function to implement the task */
      "TaskOledUpdate", /* Name of the task */
      10000,  /* Stack size in words */
      NULL,  /* Task input parameter */
      1,  /* Priority of the task */
      &Handle_TaskSSD1306,  /* Task handle. */
      0); /* Core where the task should run */

  xTaskCreatePinnedToCore(
      TaskIna219Update, /* Function to implement the task */
      "TaskIna219Update", /* Name of the task */
      10000,  /* Stack size in words */
      NULL,  /* Task input parameter */
      1,  /* Priority of the task */
      &Handle_TaskINA219,  /* Task handle. */
      0); /* Core where the task should run */

  xTaskCreatePinnedToCore(
      TaskTca8418Update, /* Function to implement the task */
      "TaskTca8418Update", /* Name of the task */
      10000,  /* Stack size in words */
      NULL,  /* Task input parameter */
      1,  /* Priority of the task */
      &Handle_TaskTCA8418,  /* Task handle. */
      0); /* Core where the task should run */

  xTaskCreatePinnedToCore(
      TaskWs2812Update, /* Function to implement the task */
      "TaskWs2812Update", /* Name of the task */
      10000,  /* Stack size in words */
      NULL,  /* Task input parameter */
      1,  /* Priority of the task */
      &Handle_TaskWS2812,  /* Task handle. */
      0); /* Core where the task should run */
}


void loop() {
  // If BLE is not connected, no-op
  if(xSemaphoreTake(bleMutex,(TickType_t)10)==pdTRUE){
    if(!ble_sleep){
      if(!bleKeyboard.isConnected()){
        ble_connected = false;
        vTaskDelay(500/portTICK_PERIOD_MS);
        ble_connect_retries++;
      }else{
        ble_connected = true;
        ble_connect_retries = 0;
      }
      if(ble_connect_retries>600){ // 600*0.5s attempts
        xSemaphoreTake(serialMutex, portMAX_DELAY);
        Serial.println("No BLE connection for 5mins, entering powersave...");
        xSemaphoreGive(serialMutex);
        peripheral_powersave();esp_deep_sleep_start();
      }
    }
    xSemaphoreGive(bleMutex);
  }
  vTaskDelay(2/portTICK_PERIOD_MS);

  // Power-down & wake-up(reset) handling
  if(!ble_sleep && (millis()-last_keypress_ms > 45*60*1000)){
    xSemaphoreTake(serialMutex, portMAX_DELAY);
    Serial.println("No keypress for 45mins, entering powersave...");
    xSemaphoreGive(serialMutex);
    peripheral_powersave();esp_deep_sleep_start();
  }
}

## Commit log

2022-10-30 <bulk> Inital Upload
    [cp2102.kicad_sch, cp2102.sch, keypad_4x4.kicad_sch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]
2022-11-02 <chore> remove anime silkscreen & gerber
    [numpad-test-B_Cu.gbr, numpad-test-B_Mask.gbr, numpad-test-B_Paste.gbr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]
2023-06-29 <docs> Update README with pics for 3d-printed parts
2023-06-29 <docs> Upload 3d models for final assembly
    [KK_numpad-case-base-18.3mf, KK_numpad-case-front-plate.3mf]
2023-06-29 <docs> Align static image with 3d model
    [numpad-case-v10.3mf]
